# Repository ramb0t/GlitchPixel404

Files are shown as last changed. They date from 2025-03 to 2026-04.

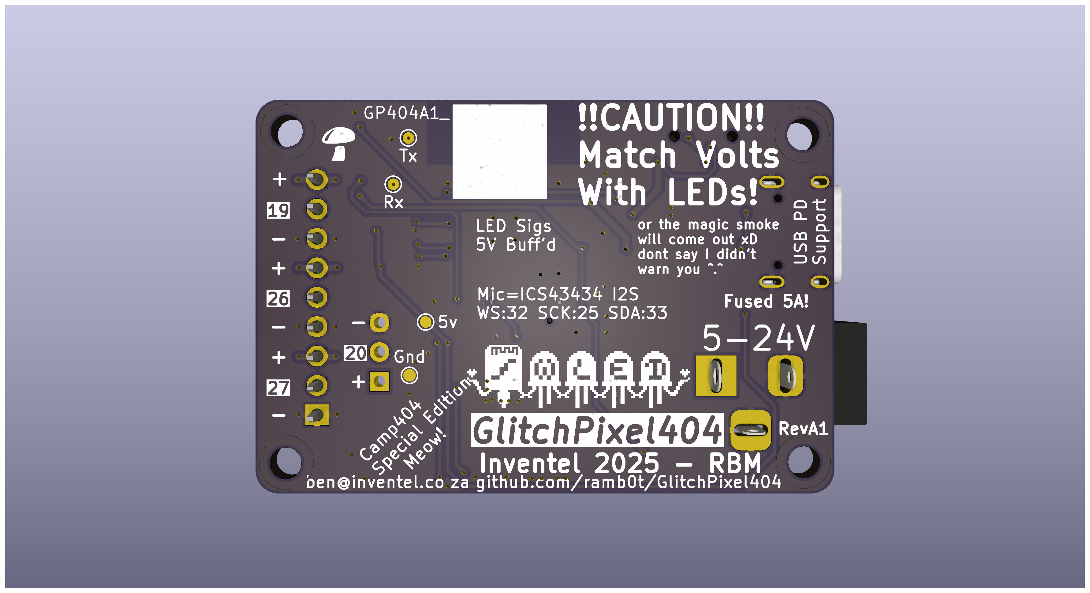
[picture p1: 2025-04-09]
images/GlitchPixel404_bottom.png

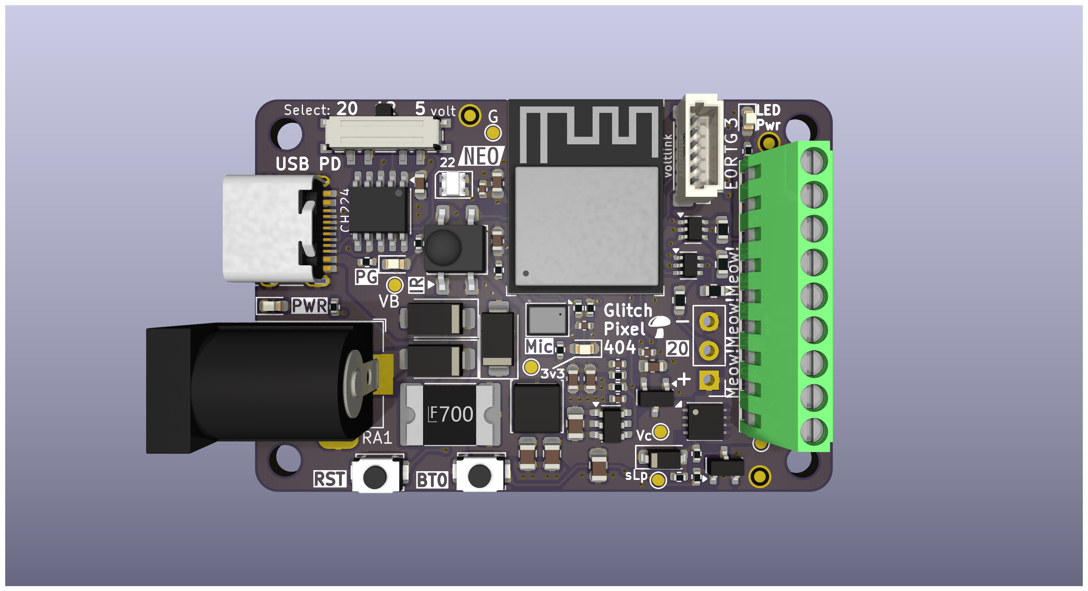
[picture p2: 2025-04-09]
images/GlitchPixel404.png

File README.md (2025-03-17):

# GlitchPixel404
A small and portable WLED driver board designed for powering digital addressable LED strips in art installations at Camp 404 during AfrikaBurn.

## Features

* Compact PCB design
* ESP32-PICO-MINI module
* 3 buffered output channels with compact screw terminals
* 5A PTC fuse protection (Global)
* Supports 5V, 12V, and 24V digital addressable LED strips
* USB-C and 2.1mm DC jack power inputs
* USB PD support for selectable 5V, 12V, or 20V output(Works with most 24V LED strips)
* MOSFET/Relay for power control of LED strips
* Single onboard Neopixel for status indication
* Onboard I2S microphone for audio-reactive effects
* Designed for a 3D printed case

## Hardware

* Based on the ESP32-PICO-MINI module.
* Insipired by the [Adafruit Sparkle Motion](https://www.adafruit.com/product/6100) controller and other OSHW WLED projects.

## Software

* Intended for use with the [WLED firmware](https://kno.wled.ge/).
* Advanced audio and group control by [LedFx](https://github.com/LedFx/LedFx) 

## License

This project is open-source under the [CC BY-SA 4.0](license.txt).

## Intended Use

Designed for powering creative LED lighting installations.

## Status

Currently in the PCB design phase.

## Contributing

Contributions are welcome!

## Acknowledgements

* This project utilises the fantastic [WLED](https://kno.wled.ge/) firmware.
* Inspired by the vibrant creativity of [Camp 404](https://github.com/404camp/) and [AfrikaBurn](https://www.afrikaburn.com/).

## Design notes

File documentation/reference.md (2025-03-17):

# WLED
[WLED](https://kno.wled.ge/)
[WLED Repo](https://github.com/wled/WLED)

# Reference Projects:

## [GlitchPixel404](https://github.com/Electronics-404/GlitchPixel404)

[MagWLED1](https://magwled.com/pages/about-magwled-1)
[Adafruit Sparkle Motion Mini](https://learn.adafruit.com/adafruit-sparkle-motion-mini/downloads)
[Adafruit Sparkle Motion Mini Repo](https://github.com/adafruit/Adafruit-Mini-Sparkle-Motion-PCB)

[Adafruit Sparkle Motion](https://learn.adafruit.com/adafruit-sparkle-motion/downloads)
[Adafruit Sparkle Motion Repo](https://github.com/adafruit/Adafruit-Sparkle-Motion-PCB)

[Yet Another WLED Controller](https://github.com/lizardsystems/yawl-controller)
[WLED ESP32 pico board](https://github.com/srg74/WLED-ESP32-pico/tree/main)
[revk ESP32-LED](https://github.com/revk/ESP32-LED)

# Design References
[Audio Reactive WLED](https://kno.wled.ge/advanced/audio-reactive/)
[WLED Audioreactive usermod docs](https://github.com/wled/WLED/tree/main/usermods/audioreactive)
ESP32 pins in the table are just examples. In fact any available GPIO can be used for I²S on ESP32.

    SD can be either an in/out pin (gpio < 34) or an input-only pin (gpi >= 34),
    while WS and SCK must be in/out pins (gpio < 34).

[Quin LED Data Resistor Testing](https://quinled.info/2021/03/10/maximum-length-data-wire-leds-ws2812b-sk6812-ws2815/)

# Other References
[Espressif PCB Layout Design](https://docs.espressif.com/projects/esp-hardware-design-guidelines/en/latest/esp32/pcb-layout-design.html)
[ESP Hardware Design Guidelines](https://docs.espressif.com/projects/esp-hardware-design-guidelines/en/latest/esp32/index.html)

# Part References
[Screw Terminal - 2.54mm pitch](https://jlcpcb.com/partdetail/Jiln-JL30825410G01/C2922605)

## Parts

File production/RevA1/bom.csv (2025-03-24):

Designator | Footprint | Quantity | Value | LCSC Part #
C1, C11, C14, C2 | 0805 | 4 | 22uF/25V | C45783
C10, C15, C3, C9 | 0603 | 4 | 22uF/6.3V | C59461
C12, C16, C4, C7 | 0402 | 4 | 100nF | C1525
C5, C6 | 0603 | 2 | 1uF | C15849
C8 | 0402 | 1 | 47pF | C1567
D1, D3 | D_SMA | 2 | SS54 | C22452
D2 | D_SMA | 1 | SMAJ24A | C3001960
D4, D6, D8, D9 | 0603 | 4 | Red | C2286
D5 | LED_WS2812B-2020_PLCC4_2.0x2.0mm | 1 | WS2812B-2020 | C965555
D7 | D_SOD-123 | 1 | 10V | C173431
F1 | 2920 | 1 | Polyfuse 5A | C20539728
J2 | USB_C_Receptacle_HRO_TYPE-C-31-M-12 | 1 | USB_C_Receptacle_USB2.0_16P | C165948
J3 | JST_SH_BM06B-SRSS-TB_1x06-1MP_P1.00mm_Vertical | 1 | VOLTLINK | C5120200
L1 | L_Changjiang_FNR4018S | 1 | 10uH | C167808
MK1 | InvenSense_ICS-43434-6_3.5x2.65mm | 1 | ICS-43434 | C5656610
Q1 | DFN-8-1EP_3x3mm_P0.65mm_EP1.5x2.25mm | 1 | AONR21357-ES | C22379638
Q2 | SOT-23 | 1 | MMBT3904 | C20526
R1, R10, R11, R13, R2, R4, R7, R9 | 0402 | 8 | 10k | C25744
R12, R3 | 0402 | 2 | 1k | C11702
R14, R15, R16, R17 | 0603 | 4 | 100R | C22775
R5, R8 | 0402 | 2 | 100K | C25741
R6 | 0402 | 1 | 22K | C25768
SW1 | SW_Push_SPST_NO_Alps_SKRK | 1 | Reset
SW2 | SW_Push_SPST_NO_Alps_SKRK | 1 | Boot
SW3 | SW_SP3T_PCM13 | 1 | SW_SP3T | C2858293
U1 | SSOP-10-1EP_3.9x4.9mm_P1mm_EP2.1x3.3mm | 1 | CH224K | C970725
U2 | ESP32-PICO-MINI-02 | 1 | ESP32-PICO-MINI-02U-N8R2 | C2980306
U3 | Everlight_IRM-H6xxT | 1 | IRM-H638T/TR2 | C91447
U4 | SOT-23-6 | 1 | TPS54202DDC | C191884
U5 | SOT-23 | 1 | HE2021A50HMR | C711948
U6, U7 | SOT-363_SC-70-6 | 2 | 74LVC2G34 | C14461

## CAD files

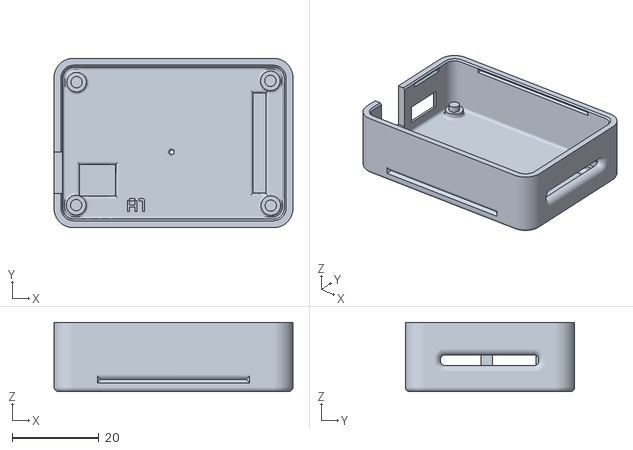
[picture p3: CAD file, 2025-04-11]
3D/GlitchPixel404_A1_Base.stl
55.0 x 39.0 x 15.9

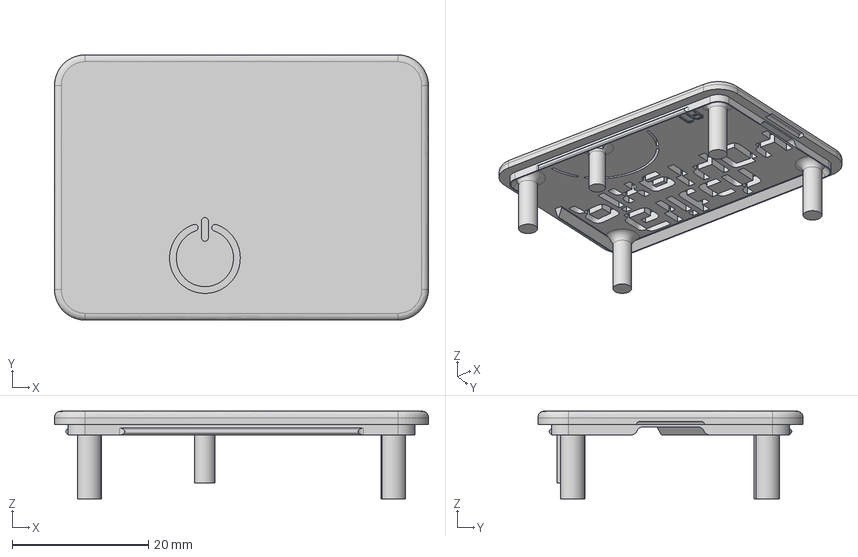
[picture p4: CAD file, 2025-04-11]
3D/GlitchPixel404_A1_Top.step
55.0 x 39.0 x 12.9 mm

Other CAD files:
3D/GlitchPixel404_A1_Top.f3d
3D/GlitchPixel404_A1_Top.stl

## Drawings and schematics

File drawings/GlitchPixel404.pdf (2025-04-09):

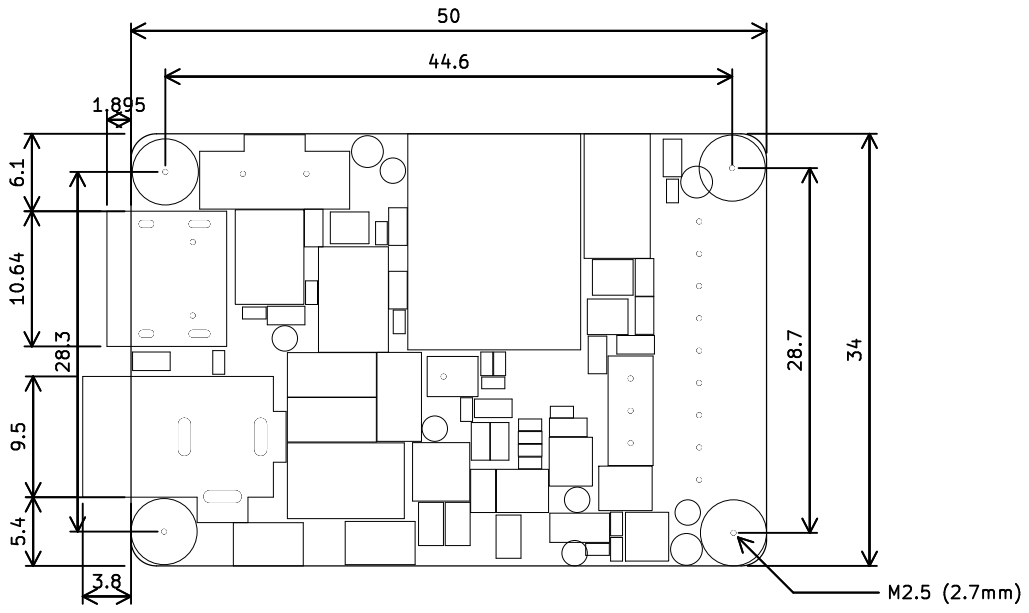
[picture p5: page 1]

Id: 1/1 Title: File: GlitchPixel404.kicad_pcb Sheet: 28.3

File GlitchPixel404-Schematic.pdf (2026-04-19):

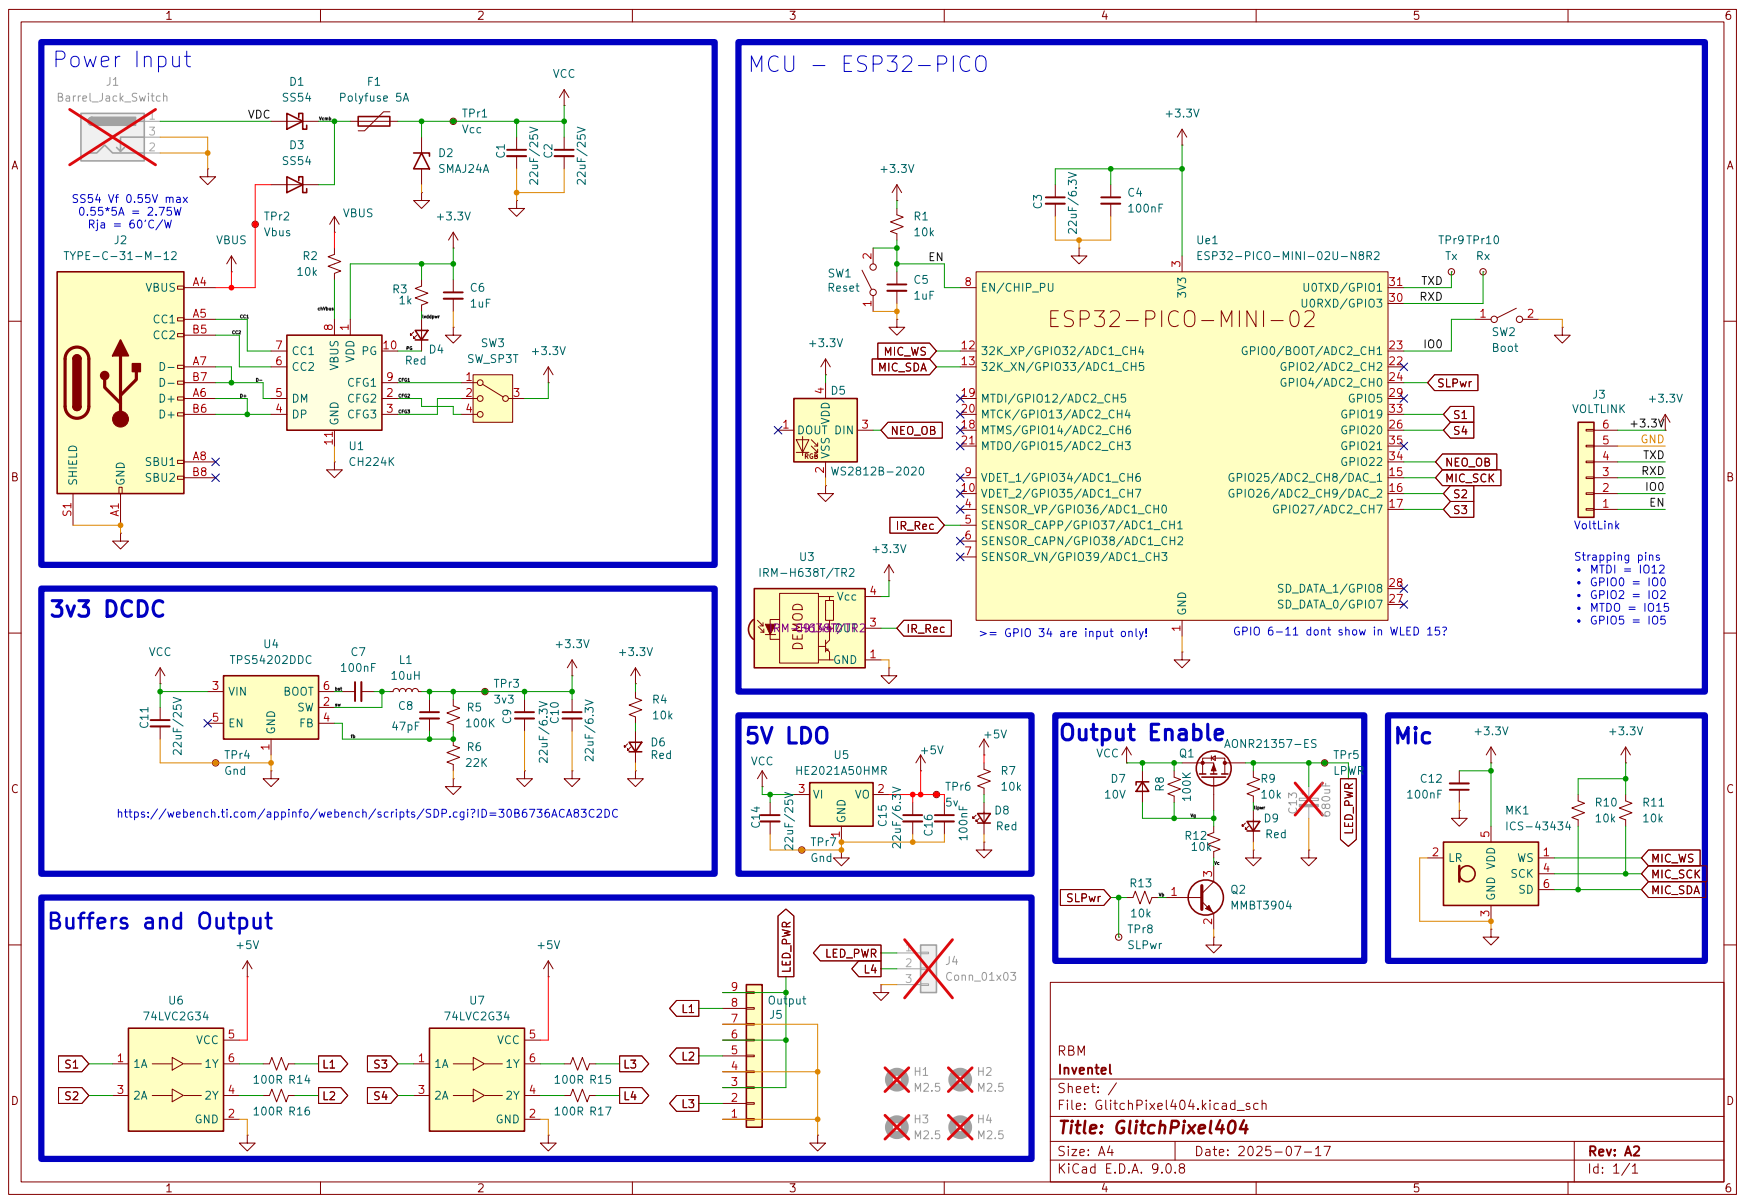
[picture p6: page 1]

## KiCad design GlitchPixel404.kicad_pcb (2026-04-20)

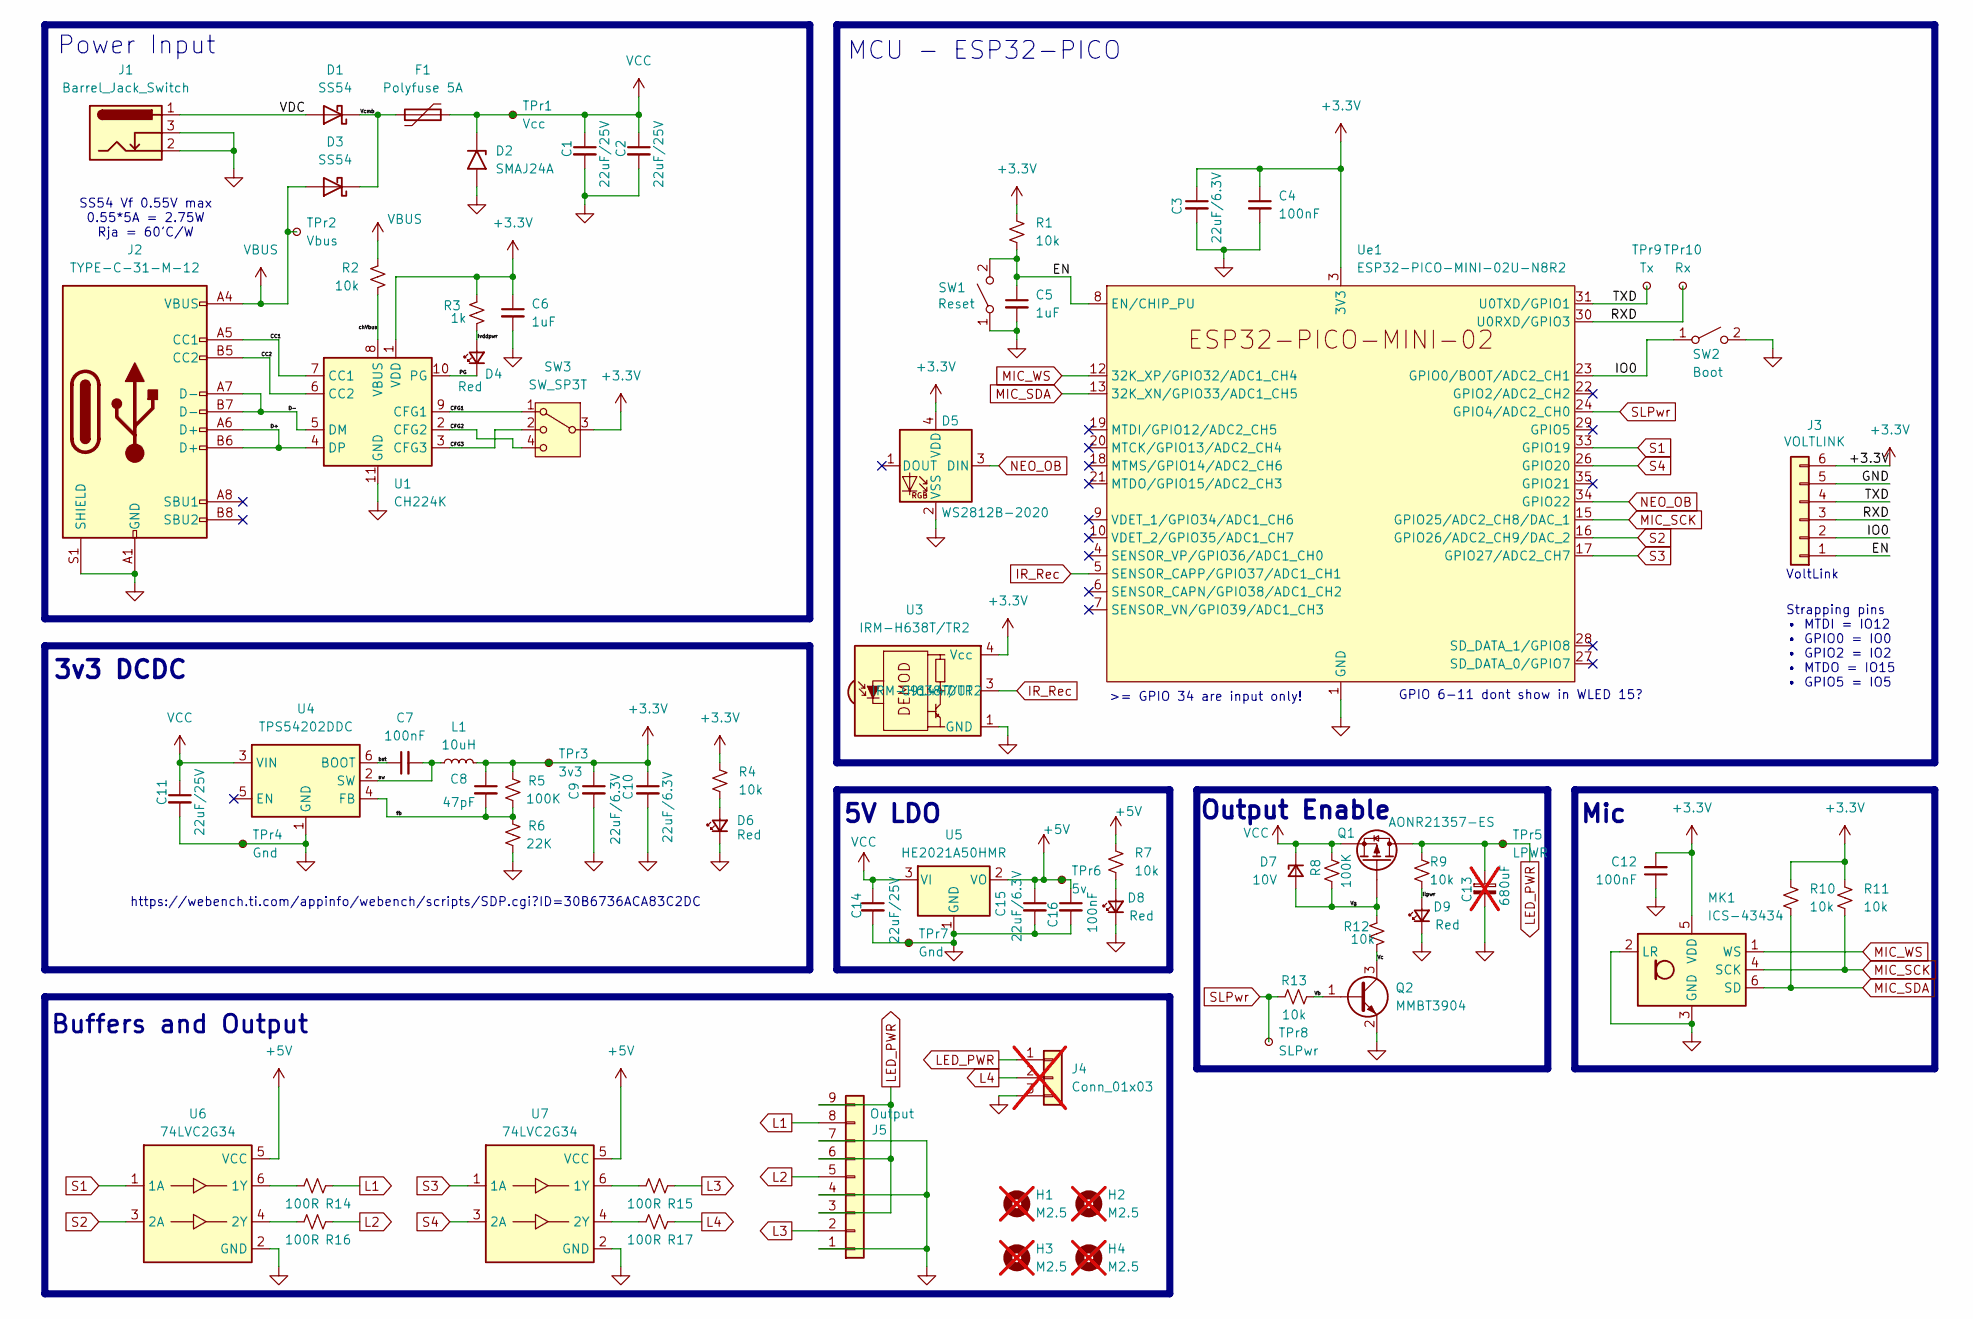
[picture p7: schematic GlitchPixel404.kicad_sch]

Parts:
C1, C2, C11, C14: 22uF/25V; C_0805_2012Metric; Voltage 25V; MPN CL21A226MAQNNNE; LCSC C45783
C3, C9, C10, C15: 22uF/6.3V; C_0603_1608Metric; MPN CL10A226MQ8NRNC; LCSC C59461
C4, C7, C12, C16: 100nF; C_0402_1005Metric; MPN CL05B104KO5NNNC; LCSC C1525
C5, C6: 1uF; C_0603_1608Metric; MPN CL10A105KB8NNNC; LCSC C15849
C8: 47pF; C_0402_1005Metric; MPN 0402CG470J500NT; LCSC C1567
C13: 680uF; CP_Elec_10x12.5; not fitted
D1, D3: SS54; D_SMA; MPN SS54; LCSC C22452
D2: SMAJ24A; D_SMA; LCSC C3001960
D4, D6: Red; LED_0603_1608Metric; MPN 19-213/Y2C-CQ2R2L/3T(CY); LCSC C2286
D5: WS2812B-2020; LED_WS2812B-2020_PLCC4_2.0x2.0mm; LCSC C965555
D7: 10V; D_SOD-123; MPN BZT52C10; LCSC C173431
D8, D9: Red; LED_0603_1608Metric; MPN 19-217/GHC-YR1S2/3T; LCSC C2286
F1: Polyfuse 5A; Fuse_2920_7451Metric; MPN BSMD2920-500-30V; LCSC C20539728
H1, H2, H3, H4: M2.5; MountingHole_2.7mm_M2.5_DIN965; not fitted
J1: Barrel_Jack_Switch; BarrelJack_Horizontal
J2: TYPE-C-31-M-12; USB_C_Receptacle_HRO_TYPE-C-31-M-12; MPN TYPE-C-31-M-12; LCSC C165948
J3: VOLTLINK; JST_SH_BM06B-SRSS-TB_1x06-1MP_P1.00mm_Vertical; MPN WTB01L06BA; LCSC C5120200
J4: Conn_01x03; PinHeader_1x03_P2.54mm_Vertical; not fitted
J5: Output; CONN-TH_9P-P2.54_MX128-2.54-09P-GN01-CU-Y-A; LCSC C5188449
L1: 10uH; L_Changjiang_FNR4018S; MPN FNR4018S100MT; LCSC C167808
MK1: ICS-43434; InvenSense_ICS-43434-6_3.5x2.65mm; LCSC C5656610
Q1: AONR21357-ES; DFN-8-1EP_3x3mm_P0.65mm_EP1.5x2.25mm; MPN AONR21357-ES; LCSC C22379638
Q2: MMBT3904; SOT-23; LCSC C20526
R1, R2, R4, R7, R9, R10, R11, R13: 10k; R_0402_1005Metric; MPN 0402WGF1002TCE; LCSC C25744
R3: 1k; R_0402_1005Metric; MPN 0402WGF1001TCE; LCSC C11702
R5, R8: 100K; R_0402_1005Metric; MPN 0402WGF1003TCE; LCSC C25741
R6: 22K; R_0402_1005Metric; MPN 0402WGF2202TCE; LCSC C25768
R12: 10k; R_0402_1005Metric; MPN 0402WGF1001TCE; LCSC C25744
R14, R15, R16, R17: 100R; R_0603_1608Metric; MPN 0603WAF1000T5E; LCSC C22775
SW1: Reset; SW_Push_SPST_NO_Alps_SKRK; MPN TS342A2P-WZ; LCSC C557591
SW2: Boot; SW_Push_SPST_NO_Alps_SKRK; MPN TS342A2P-WZ; LCSC C557591
SW3: SW_SP3T; SW_SP3T_PCM13; MPN MSK13C02-BB 125; LCSC C2858293
TPr1: Vcc; TestPoint_Pad_D1.0mm
TPr2: Vbus; TestPoint_Pad_D1.0mm
TPr3: 3v3; TestPoint_Pad_D1.0mm
TPr4, TPr7: Gnd; TestPoint_Pad_D1.0mm
TPr5: LPWR; TestPoint_Pad_D1.0mm
TPr6: 5v; TestPoint_Pad_D1.0mm
TPr8: SLPwr; TestPoint_Pad_D1.0mm
TPr9: Tx; TestPoint_Pad_D1.0mm
TPr10: Rx; TestPoint_Pad_D1.0mm
U1: CH224K; SSOP-10-1EP_3.9x4.9mm_P1mm_EP2.1x3.3mm; LCSC C970725
U3: IRM-H638T/TR2; Everlight_IRM-H6xxT; MPN IRM-H638T/TR2; LCSC C91447
U4: TPS54202DDC; SOT-23-6; LCSC C191884
U5: HE2021A50HMR; SOT-23; LCSC C711948
U6, U7: 74LVC2G34; SOT-363_SC-70-6; MPN SN74LVC2G34DCKR; LCSC C14461
Ue1: ESP32-PICO-MINI-02U-N8R2; ESP32-PICO-MINI-02; LCSC C2980306

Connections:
+3.3V: C3.1, C4.1, C6.1, C8.1, C9.1, C10.1, C12.2, D5.4 (VDD), J3.6, L1.2, MK1.5 (VDD), R1.1, R3.2, R4.1, R5.1, R10.1, R11.1, SW3.3, TPr3.1, U1.1 (VDD), U3.4 (Vcc), Ue1.3 (3V3)
+5V: C15.1, C16.1, R7.1, TPr6.1, U5.2 (VO), U6.5 (VCC), U7.5 (VCC)
/CC1: J2.A5 (CC1), U1.7 (CC1)
/CC2: J2.B5 (CC2), U1.6 (CC2)
/CFG1: SW3.1, U1.9 (CFG1)
/CFG2: SW3.4, U1.2 (CFG2)
/CFG3: SW3.2, U1.3 (CFG3)
/D+: J2.A6 (D+), J2.B6 (D+), U1.4 (DP)
/D-: J2.A7 (D-), J2.B7 (D-), U1.5 (DM)
/EN: C5.1, J3.1, R1.2, SW1.2 (B), Ue1.8 (EN/CHIP_PU)
/IO0: J3.2, SW2.1 (A), Ue1.23 (GPIO0/BOOT/ADC2_CH1)
/PG: D4.1 (K), U1.10 (PG)
/RXD: J3.3, TPr10.1, Ue1.30 (U0RXD/GPIO3)
/TXD: J3.4, TPr9.1, Ue1.31 (U0TXD/GPIO1)
/VDC: D1.2 (A), J1.1
/Vb: Q2.1 (B), R13.2
/Vc: Q2.3 (C), R12.1
/Vcmb: D1.1 (K), D3.1 (K), F1.1
/Vg: D7.2 (A), Q1.G, R8.1, R12.2
/bst: C7.1, U4.6 (BOOT)
/chVbus: R2.2, U1.8 (VBUS)
/fb: C8.2, R5.2, R6.1, U4.4 (FB)
/llpwr: D9.2 (A), R9.2
/lvddpwr: D4.2 (A), R3.1
/sw: C7.2, L1.1, U4.2 (SW)
GND: C1.2, C2.2, C3.2, C4.2, C5.2, C6.2, C9.2, C10.2, C11.2, C12.1, C13.2, C14.2, C15.2, C16.2, D2.2 (A2), D5.2 (VSS), D6.1 (K), D8.1 (K), D9.1 (K), J1.2, J1.3, J2.A1 (GND), J2.A12 (GND), J2.B1 (GND), J2.B12 (GND), J2.S1 (SHIELD), J3.5, J4.3, J5.1, J5.4, J5.7, MK1.2 (LR), MK1.3 (GND), Q2.2 (E), R6.2, SW1.1 (A), SW2.2 (B), TPr4.1, TPr7.1, U1.11 (GND), U3.1 (GND), U3.2 (GND), U4.1 (GND), U5.1 (GND), U6.2 (GND), U7.2 (GND), Ue1.1 (GND), Ue1.2 (GND), Ue1.11 (GND), Ue1.14 (GND), Ue1.36 (GND), Ue1.37 (GND), Ue1.38 (GND), Ue1.39 (GND), Ue1.40 (GND), Ue1.41 (GND), Ue1.42 (GND), Ue1.43 (GND), Ue1.44 (GND), Ue1.45 (GND), Ue1.46 (GND), Ue1.47 (GND), Ue1.48 (GND), Ue1.49 (GND), Ue1.50 (GND), Ue1.51 (GND), Ue1.52 (GND), Ue1.53 (GND)
IR_Rec: U3.3 (OUT), Ue1.5 (SENSOR_CAPP/GPIO37/ADC1_CH1)
L1: J5.8, R14.1
L2: J5.5, R16.1
L3: J5.2, R15.1
L4: J4.2, R17.1
LED_PWR: C13.1, J4.1, J5.3, J5.6, J5.9, Q1.D, R9.1, TPr5.1
MIC_SCK: MK1.4 (SCK), R11.2, Ue1.15 (GPIO25/ADC2_CH8/DAC_1)
MIC_SDA: MK1.6 (SD), R10.2, Ue1.13 (32K_XN/GPIO33/ADC1_CH5)
MIC_WS: MK1.1 (WS), Ue1.12 (32K_XP/GPIO32/ADC1_CH4)
NEO_OB: D5.3 (DIN), Ue1.34 (GPIO22)
unnamed: D6.2 (A), R4.2
unnamed: D8.2 (A), R7.2
unnamed: R14.2, U6.6 (1Y)
unnamed: R16.2, U6.4 (2Y)
unnamed: R15.2, U7.6 (1Y)
unnamed: R17.2, U7.4 (2Y)
S1: U6.1 (1A), Ue1.33 (GPIO19)
S2: U6.3 (2A), Ue1.16 (GPIO26/ADC2_CH9/DAC_2)
S3: U7.1 (1A), Ue1.17 (GPIO27/ADC2_CH7)
S4: U7.3 (2A), Ue1.26 (GPIO20)
SLPwr: R13.1, TPr8.1, Ue1.24 (GPIO4/ADC2_CH0)
VBUS: D3.2 (A), J2.A4 (VBUS), J2.A9 (VBUS), J2.B4 (VBUS), J2.B9 (VBUS), R2.1, TPr2.1
VCC: C1.1, C2.1, C11.1, C14.1, D2.1 (A1), D7.1 (K), F1.2, Q1.S, R8.2, TPr1.1, U4.3 (VIN), U5.3 (VI)

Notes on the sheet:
3v3 DCDC
Mic
Output Enable
MCU - ESP32-PICO
https://webench.ti.com/appinfo/webench/scripts/SDP.cgi?ID=30B6736ACA83C2DC
Strapping pins • MTDI = IO12 • GPIO0 = IO0 • GPIO2 = IO2 • MTDO = IO15 • GPIO5 = IO5
Power Input
>= GPIO 34 are input only!
Buffers and Output
GPIO 6-11 dont show in WLED 15?
5V LDO
VoltLink
SS54 Vf 0.55V max 0.55*5A = 2.75W Rja = 60'C/W

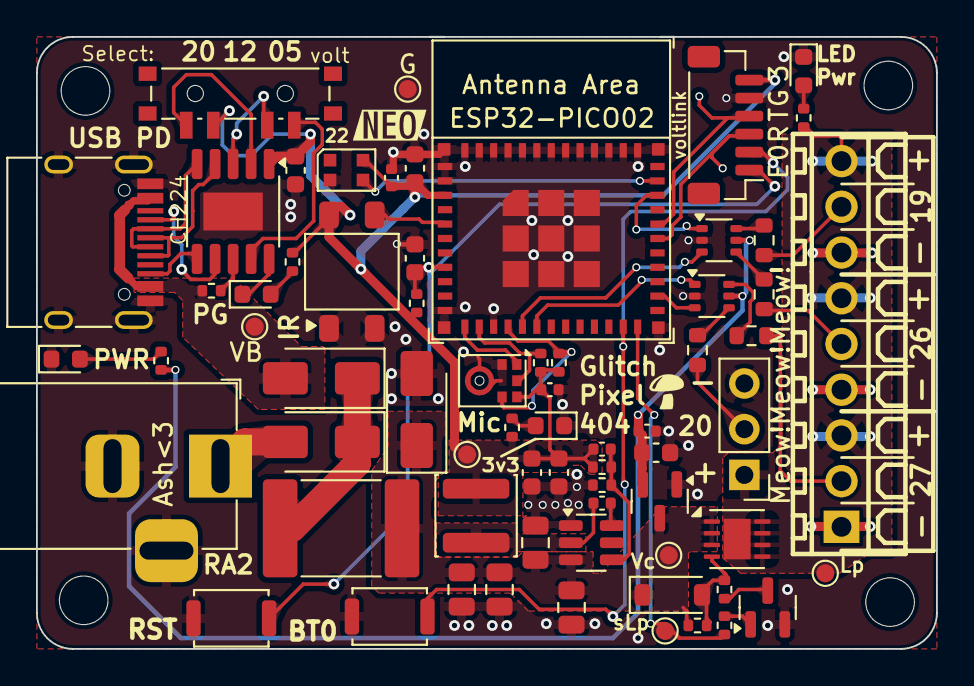
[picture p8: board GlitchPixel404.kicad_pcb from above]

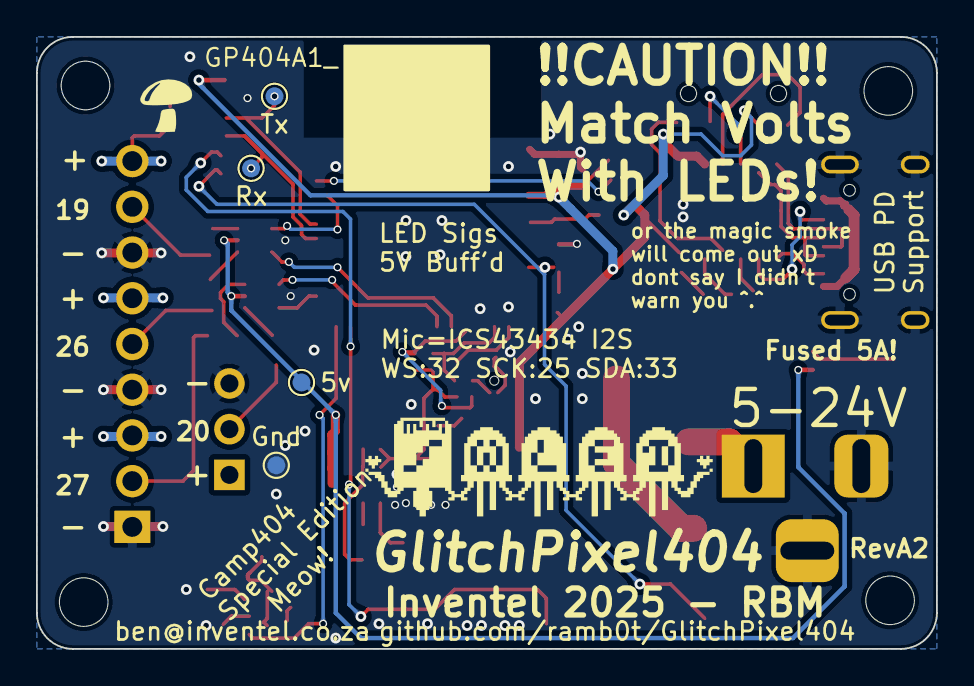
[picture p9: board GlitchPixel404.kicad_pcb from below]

Board: 2 copper layers, 50.0 x 34.0 mm, 76 parts (4 on the bottom side), 49 nets.

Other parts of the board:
kibuzzard-67E14B7B: G***; kibuzzard-67E14B7B

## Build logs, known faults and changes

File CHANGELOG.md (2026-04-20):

# Changelog

All notable changes to this project will be documented in this file.

---

## [HW Rev A2]

### Fixed
- Changed R12 1k -> 10K to correct >10v operation dissipation 

### Changed
- Minor silkscreen fixes

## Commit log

2025-03-15 Add USB PD Trig Circuit
    [GlitchPixel404.kicad_pcb, GlitchPixel404.kicad_sch]
2025-03-17 Changed buffers to 74LVC2G34 and added datasheets
    [GlitchPixel404.kicad_pcb, GlitchPixel404.kicad_sch]
2025-03-17 Added 3v3 DCDC
    [GlitchPixel404.kicad_pcb, GlitchPixel404.kicad_sch]
2025-03-17 Parts selection and 0402
    [GlitchPixel404.kicad_pcb, GlitchPixel404.kicad_sch]
2025-03-18 Added fet protection and started layout
    [GlitchPixel404.kicad_pcb, GlitchPixel404.kicad_sch]
2025-03-23 remove CH340 and start layout
    [GlitchPixel404.kicad_pcb, GlitchPixel404.kicad_sch]
2025-03-24 Layout 80% complete, some circuit changes
    [GlitchPixel404.kicad_pcb, GlitchPixel404.kicad_sch]
2025-03-24 Minor corrections, silk started
    [GlitchPixel404.kicad_pcb, GlitchPixel404.kicad_sch]
2025-03-24 Adjusted component selection
    Final silk and checks before prototype batch ready
    [GlitchPixel404.kicad_pcb, GlitchPixel404.kicad_sch]
2025-03-24 RevA1
    Sent for manufacture of prototypes
    [GlitchPixel404.kicad_pcb, GlitchPixel404.kicad_sch, bom.csv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]
2025-04-09 Add Drawings and 3D Files
    [GlitchPixel404.kicad_pcb, GlitchPixel404.kicad_sch, GlitchPixel404_A1_Base.stl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]
2025-04-11 Case Design Complete
    [GlitchPixel404.kicad_pcb, GlitchPixel404_A1_Base.stl, GlitchPixel404_A1_Top v1.f3d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]
2025-07-17 Started A2 HW Rev, Fixed R12
    [GlitchPixel404.kicad_pcb, GlitchPixel404.kicad_sch]
2026-04-19 Add schematic pdf
2026-04-20 Update silkscreen
    [GlitchPixel404.kicad_pcb, GlitchPixel404.kicad_sch]
